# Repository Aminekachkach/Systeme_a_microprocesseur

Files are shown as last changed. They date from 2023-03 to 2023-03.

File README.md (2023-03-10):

# Systeme_a_microprocesseur
This project was made by Me and my colleague Etienne PARMENTIER during our engineering studies at ENSEA.

BaudRate de l'USART2: 115200 Bits/ seconds

#TP 1.2 Questions
Q.13)
d'après la documentation technique la broche PB9 permet de permuter entre "flash program memory" et "system memory(bootloader)".
Il est important de tirer la broche en pull-down afin d'éviter qu'elle détecte un état haut au moment du reset et reflasher le mcu depuis le boot loader.

Q.14): La Bobine L1 et les capacités C5 et C7 forment un filtre de constante de temps T = 800 KHz.
Toutes les fréquences supérieures seront atténuées.

#TP 1.3 Questions
Q.3) On a les valeurs des capacités à la page 4, le schémas d'application à la page 1 permet d'être sûre que nos schémas correspondent.
Q.5) On a les valeurs des capacités à la page 25, avec le schémas qui correspond.
Q.6) La broche CS-barré est le chip select: quand elle est à l'état bas, la puce est active.
Q.7) La broche LDAC-barré synchonise le registre interne et la sortie du convertisseur.
Q.8) La broche MISO du STM32 n'est pas utilisé car aucune information n'est envoyé par le DAC au STM32. Le DAC fait juste des conversions,
Les données ne circule que dans un sens.
Q.10) Les Broches SWD sont standardisés.

#TP 1.4 Questions
Q.3) Les nombres 0805, 0603, 1206 sont les formats des boitiers des composants.
Q.4) LQFP signifie: Low Profile Quad Flat Package: La puce est basse (Low Profile), et plate (flat), et il y a des pins dans les 4 directions (Quad)
SOT-223 est un format de petit boitier pour transistor (Small Outline Transistor).
un SOIC (Small Outline Integrated Circuit) est une puce avec des pins de deux cotés, avec une épaisseur très faible.
-> Tout ces formats de puces sont montés en surface du PCB.

#TP 3.1 Questions
Q.2) Il y a beaucoup moins de fichiers générer, c'est parce-que l'on utilise des fonctions plus bas niveau sans les couches d'abstractions qu'il y a au
dessus.
Il y a beaucoup de fichiers avec __STATIC_INLINE

Q.4) __STATIC_INLINE est une macro qui contient les mots clés 'static' et 'inline'.
'static' indique au compilateur que la fonction n'est pas utilisé ailleurs que dans le fichier qui la contient.
la mise en ligne de fonction est une optimisation qui consiste à copier-coller le code de la fonction marqué 'inline'
à l'intérieur des fonctions qui l'appelle. Cela à plusieurs effets:
    - Les passe d'optimisation qui ont lieu après comme l'élimination du code mort, l'évaluation des constantes, etc... fonctionnent mieux.
    - Le code résultant est donc plus rapide, car on n'a plus besoin de sauvegarder l'état des registres dans la pile quand on appelle la fonction.
    - Dans certains cas, le code générer peut être plus gros, car les même instructions sont répétés plusieurs fois. Mais dans notre cas, les fonctions LL
    sont tellement petites que ça ne devrait pas poser de probléme. Si le compilateur calcule que plus d'instructions seront généré, il ne fera pas d'inlining.

Q.5) Le code est dans un fichier .h car du coup chaque 'compile unit' dois connaître la définition des fonctions à inliner, ce qui n'est pas nécéssaire
quand le code de chaque module est compilé séparement et qu'ils appellent des fonctions selon la convention d'appel standard du langage C.

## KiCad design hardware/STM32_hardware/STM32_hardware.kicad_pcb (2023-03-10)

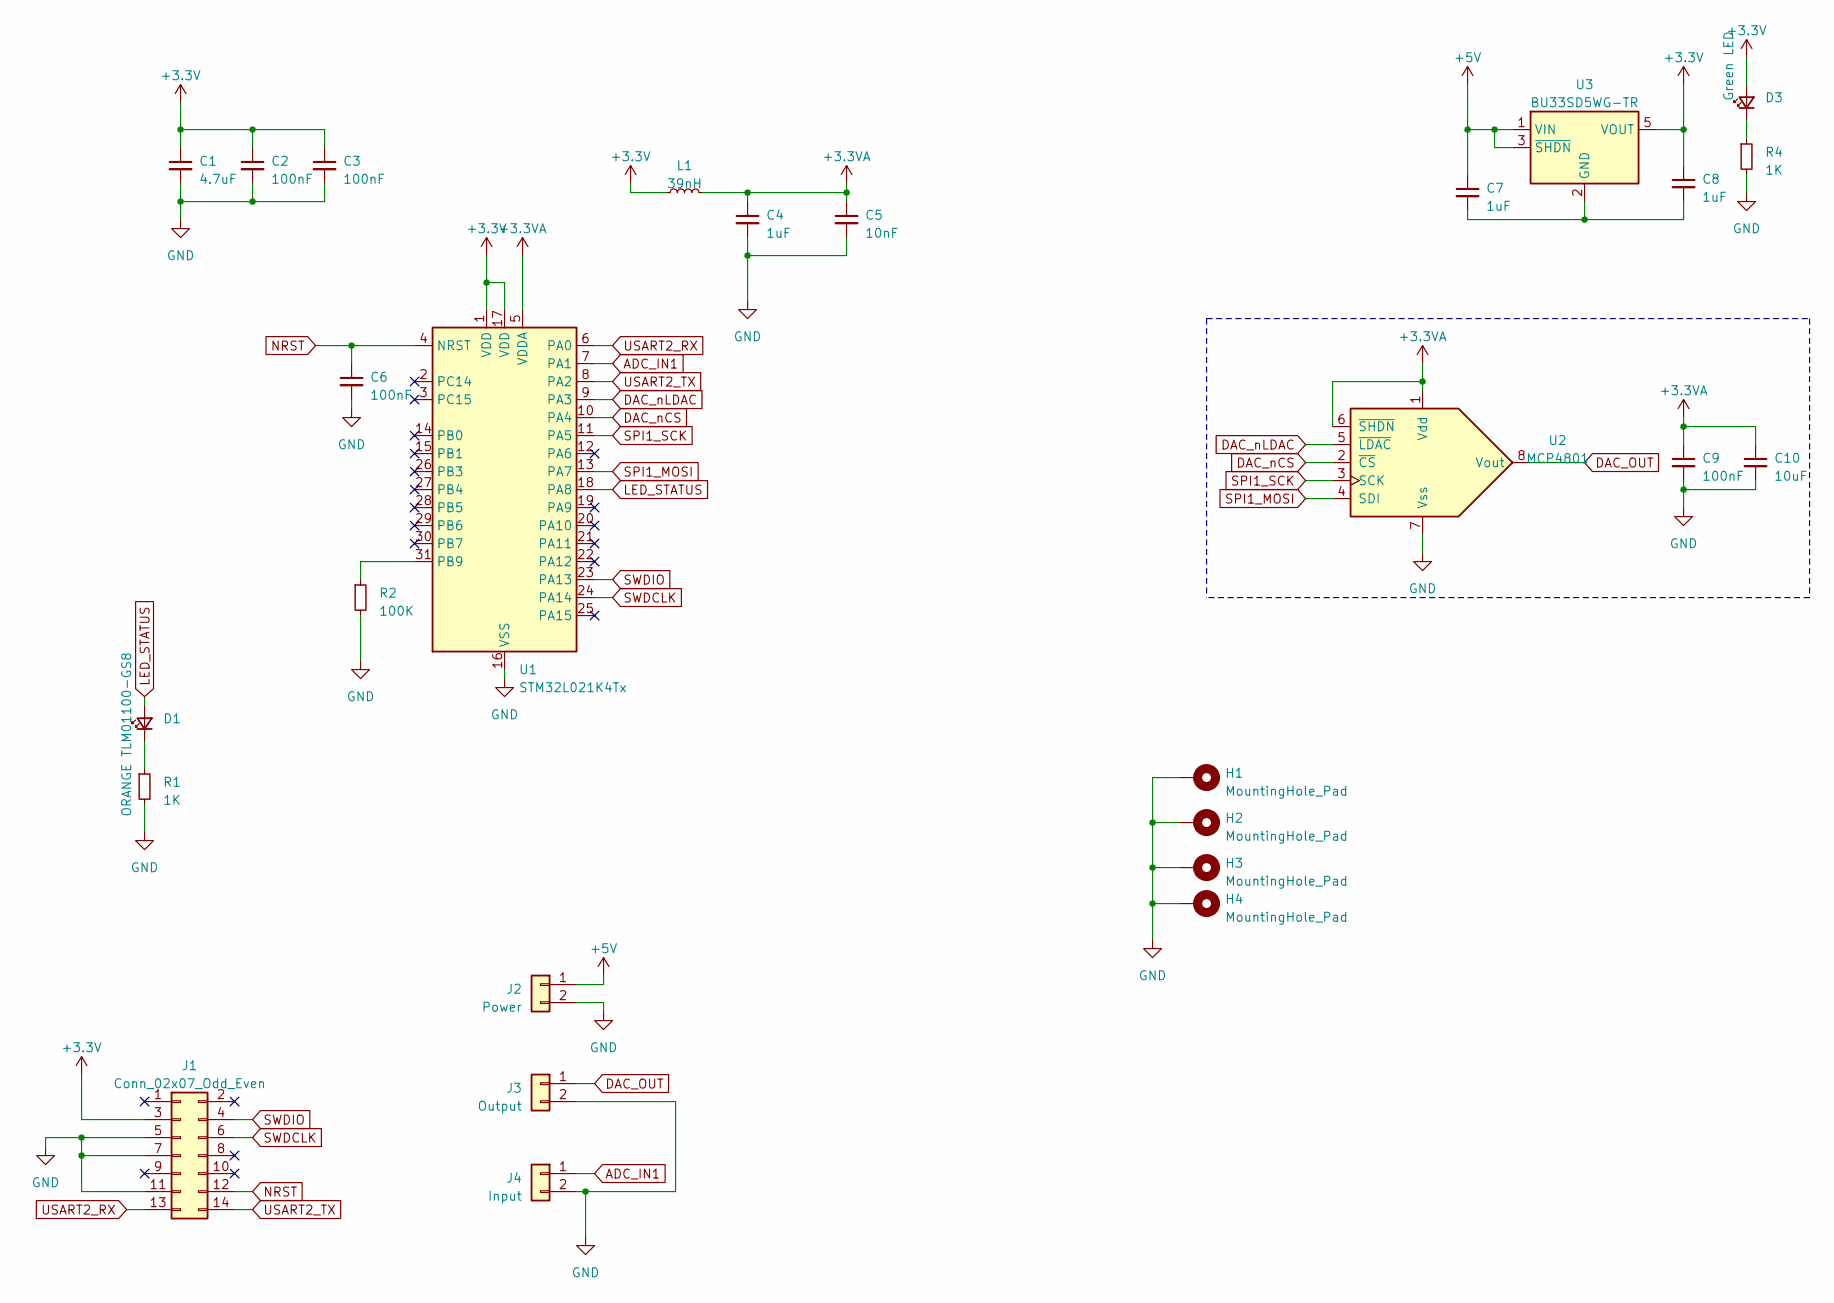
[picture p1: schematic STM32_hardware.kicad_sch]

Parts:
C1: 4.7uF; C_0805_2012Metric_Pad1.18x1.45mm_HandSolder
C2, C3, C6, C9: 100nF; C_0805_2012Metric_Pad1.18x1.45mm_HandSolder
C4, C7, C8: 1uF; C_0805_2012Metric_Pad1.18x1.45mm_HandSolder
C5: 10nF; C_0805_2012Metric_Pad1.18x1.45mm_HandSolder
C10: 10uF; C_0805_2012Metric_Pad1.18x1.45mm_HandSolder
D1: ORANGE TLM01100-GS8; LED_0603_1608Metric_Pad1.05x0.95mm_HandSolder
D3: Green LED; LED_0603_1608Metric_Pad1.05x0.95mm_HandSolder
H1, H2, H3, H4: MountingHole_Pad; MountingHole_3.2mm_M3_Pad
J1: Conn_02x07_Odd_Even; PinHeader_2x07_P1.27mm_Vertical_SMD
J2: Power; JST_XH_B2B-XH-A_1x02_P2.50mm_Vertical
J3: Output; JST_XH_B2B-XH-A_1x02_P2.50mm_Vertical
J4: Input; JST_XH_B2B-XH-A_1x02_P2.50mm_Vertical
L1: 39nH; L_0805_2012Metric_Pad1.05x1.20mm_HandSolder
R1, R4: 1K; R_0805_2012Metric_Pad1.20x1.40mm_HandSolder
R2: 100K; R_0805_2012Metric_Pad1.20x1.40mm_HandSolder
U1: STM32L021K4Tx; LQFP-32_7x7mm_P0.8mm
U2: MCP4801; SOIC-8_3.9x4.9mm_P1.27mm
U3: BU33SD5WG-TR; SOT-23-5

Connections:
+3.3V: C1.1, C2.1, C3.1, C8.1, D3.2 (A), J1.3, L1.1, U1.1 (VDD), U1.17 (VDD), U3.5 (VOUT)
+3.3VA: C4.1, C5.1, C9.1, C10.1, L1.2, U1.5 (VDDA), U2.1 (Vdd), U2.6 (~SHDN)
+5V: C7.1, J2.1, U3.1 (VIN), U3.3 (~SHDN)
ADC_IN1: J4.1, U1.7 (PA1)
DAC_OUT: J3.1, U2.8 (Vout)
DAC_nCS: U1.10 (PA4), U2.2 (~CS)
DAC_nLDAC: U1.9 (PA3), U2.5 (~LDAC)
GND: C1.2, C2.2, C3.2, C4.2, C5.2, C6.2, C9.2, C10.2, H1.1, H2.1, H3.1, H4.1, J1.5, J1.7, J1.11, J2.2, J3.2, J4.2, R1.2, R2.2, R4.2, U1.16 (VSS), U1.32 (VSS), U2.7 (Vss)
LED_STATUS: D1.2 (A), U1.18 (PA8)
NRST: C6.1, J1.12, U1.4 (NRST)
unnamed: D1.1 (K), R1.1
unnamed: D3.1 (K), R4.1
unnamed: R2.1, U1.31 (PB9)
unnamed: C7.2, C8.2, U3.2 (GND)
SPI1_MOSI: U1.13 (PA7), U2.4 (SDI)
SPI1_SCK: U1.11 (PA5), U2.3 (SCK)
SWDCLK: J1.6, U1.24 (PA14)
SWDIO: J1.4, U1.23 (PA13)
USART2_RX: J1.13, U1.6 (PA0)
USART2_TX: J1.14, U1.8 (PA2)

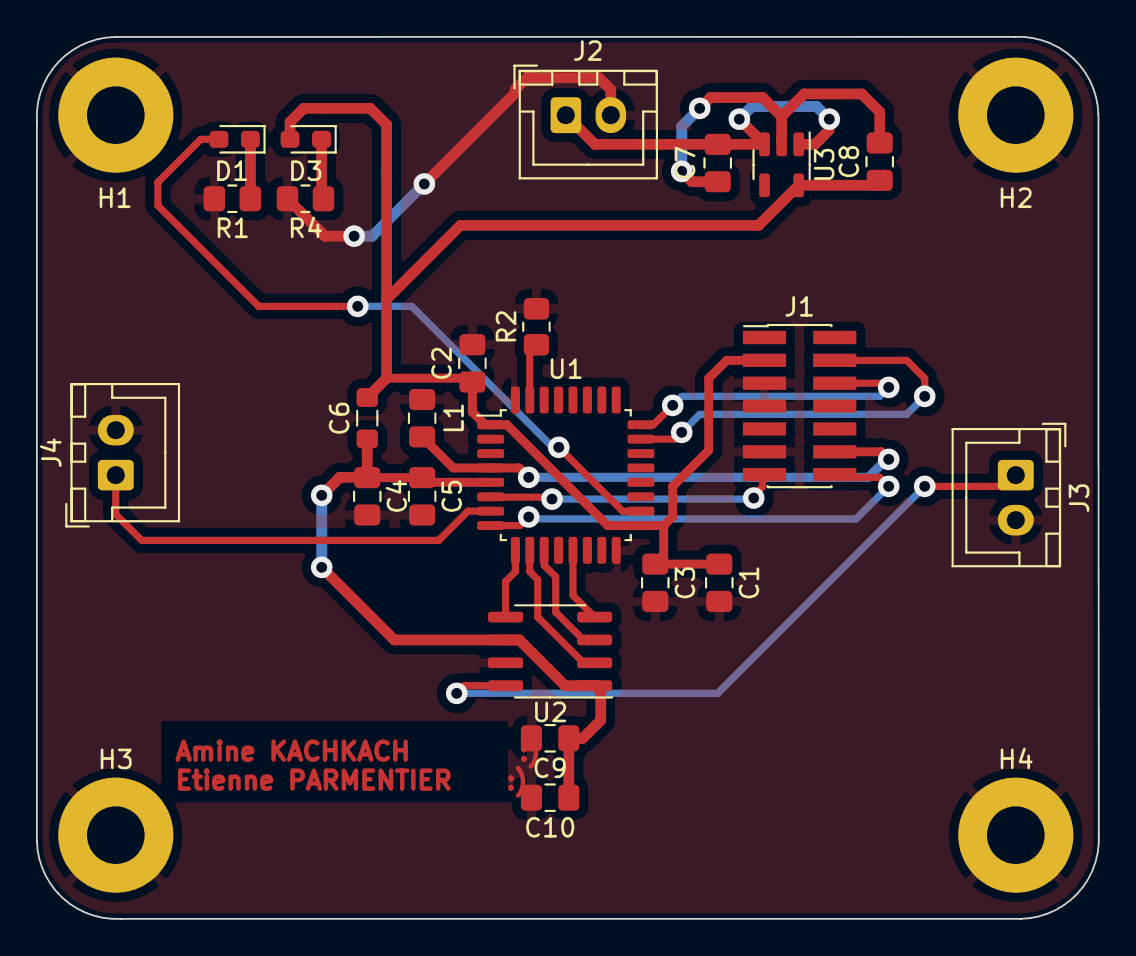
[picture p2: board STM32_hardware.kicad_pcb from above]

Board: 2 copper layers, 59.0 x 49.0 mm, 27 parts (0 on the bottom side), 20 nets.

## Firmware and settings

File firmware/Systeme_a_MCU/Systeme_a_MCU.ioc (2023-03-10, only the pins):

Mcu.UserName=STM32L021K4Tx
PA0-CK_IN.Signal=USART2_RX
PA1.Signal=ADC_IN1
PA13.Signal=SYS_SWDIO
PA14.Signal=SYS_SWCLK
PA2.Signal=USART2_TX
PA3.GPIO_Label=DAC_nLDAC
PA3.Signal=GPIO_Output
PA4.GPIO_Label=DAC_nCS
PA4.Signal=GPIO_Output
PA5.Signal=SPI1_SCK
PA7.Signal=SPI1_MOSI
PA8.Signal=S_TIM2_CH1

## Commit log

2023-02-15 Fully Configured pinout
    [System_a_mcu.kicad_pcb, System_a_mcu.kicad_sch]
2023-02-15 Renamed and discarded dupliacte directories
    [STM32_hardware.kicad_pcb, STM32_hardware.kicad_sch, System_a_mcu.kicad_pcb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]
2023-02-15 Correction de la question 14
2023-02-15 schema de principe
    [STM32_hardware.kicad_pcb, STM32_hardware.kicad_sch]
2023-03-10 Replaced HAL Drivers with Low Level Drivers
    [Systeme_a_MCU.ioc]
